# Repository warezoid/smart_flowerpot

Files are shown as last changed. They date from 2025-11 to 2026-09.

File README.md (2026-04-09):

# Smart flowerpot
The aim of the project is to create a self-sufficient and ECO-friendly planter for growing vegetables.

## Project roadmap
1. Hardware completation - finish hardware assemblies and subassemblies.
    - Drainage vent - finished.
    - Roulette system - working on.
    - Flower vent system
2. Sensors completation - solve sensor placement and data gathering.
3. User interface - create user interface with graphs, controls, logs, ...

## TODOs
- Debug drainage vent driving circuit.

- Redesign and make roulette guides.
- Program roulette driver code.

## Outdated model photos
CAD of roulette system. 
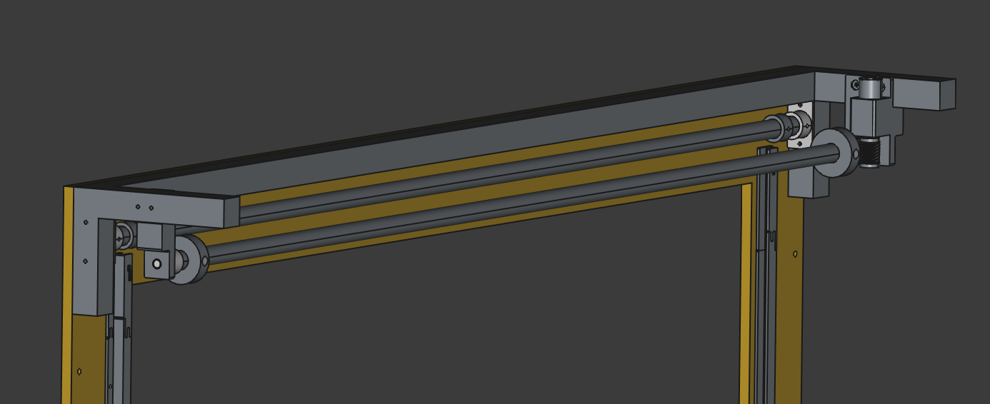
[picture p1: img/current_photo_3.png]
Outdated model photo.


CAD of drainage vent system.
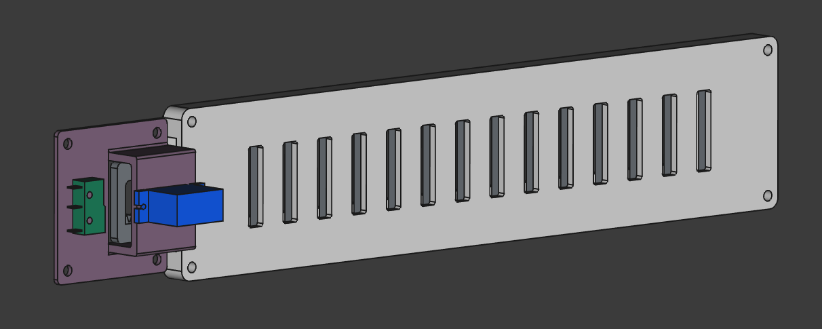
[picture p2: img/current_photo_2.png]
Outdated model photo.


CAD of older smart flower assembly.
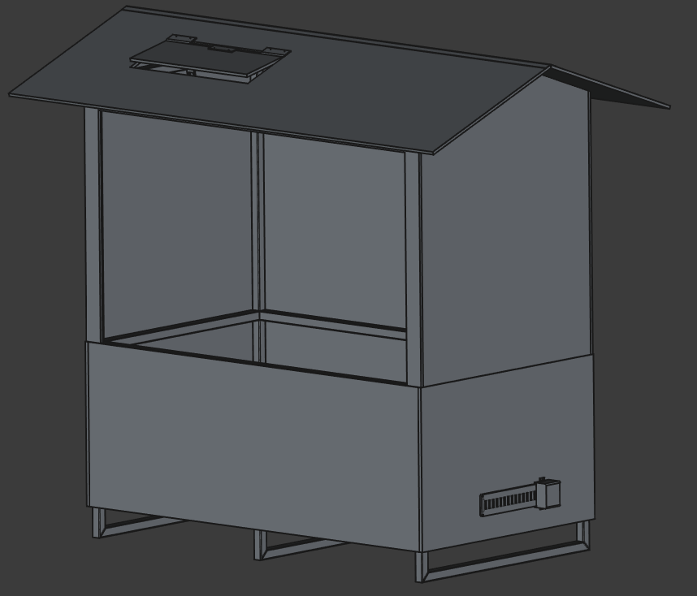
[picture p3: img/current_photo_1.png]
Outdated model photo.


###### Created by warezoid with the love of freedom and numbers.

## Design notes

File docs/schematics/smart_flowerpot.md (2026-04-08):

# Smart flowerpot
This document is overview of progress and TODOs on smart flowerpot project.

## Construction - **COMPLETE BY THE END OF MAY**
- Finish welding:
    - Weld roof and bottom together.
    - Grind all welds.
    - Check length, perpendicularity and levelness.
    - Paint construction by some color.
    - Update warezoid.com page: update metal profile photo and finished steel frame.
    - Add FEM section of metal frame.

- OSB + polycarbonate:
    - Plan OSB and polycarbonate from walls and roof - create CAD files.
        - https://www.hornbach.cz/p/polykarbonatova-deska-bravo-dutinkova-3000-x-1050-x-10-mm-cira/8234584/
    - OSB FEM sources:
        - https://www.drevoostrava.cz/cz/osb-desky/ostra-hrana/3-swiss-krono-osb-3-18-x-1250-x-2500.html?varianta=3
        - https://regata.b-cdn.net/media/folio3/productattachments/SKHU_Technical_Data_EN_2025_03_03.pdf
        - https://europanels.org/the-wood-based-panel-industry/types-of-wood-based-panels-economic-impact/oriented-strand-board/
        - https://hrcak.srce.hr/file/263350

## ESP32 / DRIVERs / MOTION

### Drainage vent
- Repair vent driver electronics (**FINISH TILL 11. APR 2026**):
    - Resolder new servo.
    - Assembly new ESP32 on a board.
    - Test for shorts, poor soldering and wire brakes.
    - Put circuit description on board.

- Program update (**FINISH TILL 12. APR 2026**):
    - Update file structure of project.
    - Update GPIOs names and check their numbers to be compatible with *smartflowerpot_tech_db*.
    - Test software with hardware.

- Create servo case:
    - Plan case for vent servo and RJ45 mini-board.
    - Make CAD model - include cabel input with some default protection.
    - Print cases and add them to test stand.

## SO
- Research:
    - Grandma
    - github.com/honzagalajda

- Consultation:
    - Marťas
    - github.com/MichalKonvic
    - github.com/zombon1

- Making stage help:
    - Honzajs

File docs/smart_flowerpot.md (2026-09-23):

# Smart flowerpot
This document is overview of progress and TODOs on smart flowerpot project.

## TODOs
- Add some RPI web server notes - MAN/AUTO mode, ...

## To buy
- Flower vent:
    - BOTTOM VENT:                   
        - MOTOR DRIVERS: https://botland.cz/ovladace-motoru-moduly/22594-mp6550-jednokanalovy-ovladac-motoru-22v-17a-pololu-4733.html

## Project roadmap
- Version 1: create functional sample of smart flowerpot.
    - Current phase:
        - Mechanical phase:
            - Create and make smartflowerpot structure.
            - Steel frame, OSB, polycarbonate, 3d printing.
            - CAD, FEM, 3d printing.
            - Output should be physical structure of smartflowerpot without drivers, sensors and electronics.

        - Driver phase:
            - Create hardware and software drivers for smart flowerpot.
            - Drainage vent, roulette, flower vent & roof vent.
            - Water circuit driver, solar power recharge.
            - Software, hardware, electronics.
            - Output should be functional drivers.

    - Sensor phase:
        - Place sensors for watering, overview, ventilation, ...
        - Create some algorithms for data procesing.
        - Output should be updated table with sensor data.
        - Coding, electronics, logic, simple table database.

    - Master-slave phase:
        - Create communication between MASTER (RPi) and multiple slaves (ESP32).
        - Send commands from MASTER to SLAVE, which will reply.
        - Start self-hosting webserver on RPi.
        - Create simple web GUI which will serve as commands IO.

    - Advanced master-slave phase:
        - RPi will get data from sensor ESP32 and store them in some local copy for overviews and commands.
        - Data will be checked and if needed drivers will be called to do some action.
        - Drivers will reply with action status and process is done.
        - Update GUI to more profesional form - overviews, logs, ...

- Version 1.1: fix bugs. Write potentional future improvements. See if second roulette is needed.
    - Solve some better system for holding hall sensors than hot glue - easier calibration.

- Version 2: add IR camera and add some machine vision. Pests monitoring.

## Construction
- OSB:
    - Cut needed holes into OSBs, grind them.
    - Grind some edge on roullete OSB hole - bottom edge of roulette window, roulette hit it and can be stucked (only on it's way down).
    - Paint OSBs by some protective paint.
    - Drill holes for OSBs mounting.
    - Add thread to the holes.
    - Repaint steel construction - drilled holes only.
    - Mount walls to the steel construction.

    - OSB FEM sources:
        - https://www.drevoostrava.cz/cz/osb-desky/ostra-hrana/3-swiss-krono-osb-3-18-x-1250-x-2500.html?varianta=3
        - https://regata.b-cdn.net/media/folio3/productattachments/SKHU_Technical_Data_EN_2025_03_03.pdf
        - https://europanels.org/the-wood-based-panel-industry/types-of-wood-based-panels-economic-impact/oriented-strand-board/
        - https://hrcak.srce.hr/file/263350

- Post-finish works:
    - Update metal profile photo and finished steel frame section.
    - Add FEM section of metal frame.

- Polycarbonate:
    - Plan OSB and polycarbonate from walls and roof - create CAD files.
        - https://www.hornbach.cz/p/polykarbonatova-deska-bravo-dutinkova-3000-x-1050-x-10-mm-cira/8234584/

## ESP32 / DRIVERs / FLOWER VENT
- Create some ventilation system for flowers:
    - Add big holes to bottom section of side OSBs with some simple ventilation - OPEN, CLOSE states.
    - Also add smaller holes to top of sided OSBs, also with some simple ventilation.
    - At top holes add fans, to create some wind channel.

- TOP vent:
    - Solve construction of top vent.
    - Solve fan system.

- BOTTOM vent:
    - *TODOs*:
        - Make hole in both shafts bigger on motor side - from 5 mm to 6 mm.
        - Think about ideal screw rod length. Cut it and file it.
        - Print motor holder, rod holder and flange, to future test.
        - Try to build some test stand - without doors.
        - Create doors.

    - Use construction of two trapezoidal screws.
    - One motor through shaft will be rotating with screw rod. Slider will be attached to desk.
    - At top will be some flange and belt transfering rotation to second pair of rods.
    - At bottom position and top position will be limit switches.
    - I also want to add some linear position measurement, for future use - some PID regulation of position. For example vent will be open to 50 %, 20 %, 75 %, ...
    - I would buy trapezoidal screws with slider, shaft, motor (if needed also with driver), LS, linear position measurement, belt, ball bearings.
    - I would print flanges, maybe belt holders, desk holders, other holders, ...

## ESP32 / DRIVERs / MOTION
- Check driver schematics with real circuit and update it if needed.
- Check CAD files if they are same as reality.

- Upgrade Excel table.
    - Separate MOTION to diferent lists, ....
- Create bill of material table for all drivers.

- Do some last testing of circuit before epoxy cover.
- Cover circuit in epoxy resin to prevent shorts and add some protection.

### Roulette
- Recalibrate TOP Hall sensor - TOP GREEN probably.

## Documentation

### warezoid.com
- Project description.
- Pictures.
- Guide.
- TODOs.
- Roadmap.
- DOCs.
- Download links.

### Documentation
- Construction: steele frame, OSB, polycarbonate, FEM.
- Drivers: drainage vent system, roulette system, flower vent system.
- Sensors, RPI server, communication, ...

## SO
- Research:
    - Grandma
    - github.com/honzagalajda

- Consultation:
    - Marťas
    - github.com/MichalKonvic
    - github.com/zombon1

- Making stage help:
    - Honzajs

## Notes

### Drivers/FLOWER VENT
- Flower vent:
    - BOTTOM VENT (only one piece):
        - MOTOR (1 pcs / 258 CZK): https://www.laskakit.cz/motor-jgy-370-12v-s-prevodovkou/
        - SHAFT (1 pcs / 44 CZK): https://www.laskakit.cz/pruzna-spojka-hlinikova-sviraci-5x8mm/
        - SCREW (1 pcs / 322 CZK): http://www.snailshop.cz/t8/2832-pohybovy-sroub-t8-500mm.html
        - NUT (2 pcs / 144 CZK): http://www.snailshop.cz/t8/2375-matice-s-prirubou-t8-mosaz.html
        
        - PULLEY (2 pcs / 112 CZK): http://www.snailshop.cz/remenice-gt2-oble-zuby/2354-remenice-gt2-20-zubu-dira-8mm.html
        - BELT (1 pcs / 76 CZK): http://www.snailshop.cz/remeny-gt2-oble-zuby/2586-ozubeny-remen-gt2-160-zubu-320mm.html
        - WORM SCREW (3 packs / 24 CZK): http://www.snailshop.cz/m3/1992-sroub-staveci-m3x5-4ks.html
        - BEARING (10 pcs / 200 CZK): http://www.snailshop.cz/bez-priruby/2826-688-lozisko-8x16x5.html
            
        - MOTOR DRIVERS: https://botland.cz/ovladace-motoru-moduly/22594-mp6550-jednokanalovy-ovladac-motoru-22v-17a-pololu-4733.html

### Drivers/MOTION/Drainage vent
- FSM:
    - IDLE (0):
        - Scan for process code. If process code (in control byte) is 00 then break. If not, then copy&paste control byte process code to temporary byte process code. Set state machine to 1 and breake.
        - Commands will be set by process code bits: 00 non active, 01 opening, 10 closing, 11 spare, in future maybe calibration.
        - Program will read only from temporary process code, which can be set only in IDLE, so overriding should be solved.
    
    - Start 1 (1):
        - If vent 1 is enabled then set action_start_ticks, set power mosfet 1 to ON, and set PWM for given operation for vent 1. Then set state machine to 2 and break.
        - Otherwise set state machine to 3 and break.

    - Moving 1 (2):
        - Check for given limit switch and if switch is active then switch off PWM, set power mosfet 1 to OFF and null action_start_ticks. Set state machine bit to 3 and break.
        - If limit switch is not active, then check if current_ticks - action_start_ticks are bellow given time interval. If yes, just break. If no, then  switch off PWM, set power mosfet 1 to OFF and null action_start_ticks and block vent 1 - set vent 1 enable bit to 0. Then set state machine bit to 3 and break.

    - Start 2 (3):
        - If vent 2 is enabled then set action_start_ticks, set power mosfet 2 to ON, and set PWM for given operation for vent 2. Then set state machine to 4 and break.
        - Otherwise set state machine to 5 and break.

    - Moving 2 (4):
        - Check for given limit switch and if switch is active then switch off PWM, set power mosfet 2 to OFF and null action_start_ticks. Then acknowledge - set vent 2 enable bit to 1. Set state machine bit to 5 and break.
        - If limit switch is not active, then check if current_ticks - action_start_ticks are bellow given time interval. If yes, just break. If no, then  switch off PWM, set power mosfet 2 to OFF and null action_start_ticks and block vent 2 - set vent 2 enable bit to 0. Then set state machine bit to 5 and break.
    
    - Finish (5):
        - Null control byte process code, temporary process code.
        - Set state machine bit to 0 and breake.

### Drivers/MOTION/Roulette
- FSM:
    - IDLE (0):
        - Scan for process code. If process code (in io_byte) is 00 then break. If not, then copy&paste io_byte process code to temporary byte process code. Set state machine to 1 and breake.
        - Commands will be set by process code bits: 00 non active, 01 opening, 10 closing, 11 spare, in future maybe calibration.
        - Program will read only from temporary process code, which can be set only in IDLE, so overriding should be solved.
    
    - Start 1 (1):
        - If roulette is enabled then set action_start_ticks, set direction pins and enable to ON. Then set state machine to 2 and break.
        - Otherwise set state machine to 4 and break.

    - Moving 1 (2):
        - Check for given limit switch and if one of them is active then switch off enable pin, null action_start_ticks and set direction pins to 0. Set state machine bit to 3 and break.
        - If limit switch is not active, then check if current_ticks - action_start_ticks are bellow given time interval. If yes, just break. If no, then switch off enable pin, set direction pins to 0, null action_start_ticks and block roulette 1 - set roulette 1 enable bit to 0. Then set state machine bit to 4 and break.

    - Acknowledge (3):
        - Check if both limit switch for given movement are active, if not then alarm user but not block the code. If yes just ignore it. Set it to 4 and break.

    - Finish (4):
        - Null control byte and io_byte process code, temporary process code.
        - Set state machine bit to 0 and breake.

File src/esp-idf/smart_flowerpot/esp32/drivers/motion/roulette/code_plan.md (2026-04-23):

# Roulette driver

## Code
1. Debuging.

## Problems
- Main problem is that I need somehow always stop the motor -> without relaying on ESP or some driver.
    - Potentional solution:
        - Physicly add some guards which will block weight from some places - bellow and above guides.
        - Normal run -> hall effect sensors connected to ESP.
            - Weight magnet reference with sensor -> ESP get notification -> switch off motor power.
            - Operation will set check index and ESP will check it in main program loop. (index 0 -> check nothing, index > 0 -> check up, index < 0 -> check down)
            - To stop motor 2 sensors will be in OR mode, to check if position is valid use AND mode.
        - Emergency -> limit switch (msw13 microswitch) physicaly behind hall efffect sensor (upper or lower) -> normaly close -> in series with motor power -> if active (error) motor shuts down.
            - This is emergency stop in electrical layer.
            - If ESP goes down -> no problem -> NC switch connected with motor power in series.
            - If motor or motor driver goes down -> motor will not spin -> no problem -> ESP set motor to block and sent alerts.
        - Emergency 2 -> try to get motor driver with overcurrent protection -> if motor is drawing too much current it will switch off power to motor.
            - Use MP6550 motor driver.

## Code diagram
1. Get OPEN/CLOSE request.
2. If operation open/close isn't already running then do:
    1. If roulette is not blocked then do:
        1. Set motor direction.
        2. Set Hall effect check index - lower or higher hall effect will be checked.
        3. Switch on power to motor & Start callback timer and ticks.
        4. Check for Hall effect senzor status change.
            1. If valid status changed then switch off power to motor - main switch off!
            - There are two hall effect sensors for top and two for bottom.
            - In this checkout hall effect sensors in one section will work in OR mode -> one or both must be active else dont stop.
        5. After timer collapse callback will switch off power to motor - EVERYTIME - emergency switch off!
        6. After ticks collapse check if roulette is in valid position if not:
            1. Set roulette to blocked status.
            - In this checkout hall effect sensors in one section will work in AND mode -> both must be active else block.
        7. Clear ticks, hall effect check index, ...
        8. Return.
3. Ignore request.

- DIR signal will be same for both roulettes. Signals 11 and 00 means non active state. 01 is direction one and 10 is direction two.
- Motor will be stoped by driver electronics.
- ESP only set enable signal and read limit switches. ESP can also block one roulette.
- Roulette default state is CLOSED.
- ESP have to drive Enable and DIR signals.

##### Created by warezoid with the love of freedom and numbers <3

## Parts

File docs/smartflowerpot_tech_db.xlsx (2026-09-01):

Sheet: MAIN
MAIN
FOLDER STRUCTURE
LAYER 1 | LAYER 2 | LAYER 3 | LAYER 4 | LAYER 5 | LAYER 6 | LAYER 7 | LAYER 8 | LAYER 9 | LAYER 10
smart_flowerpot | esp32 | drivers | motion | drainage_vent | include | drainage_vent.h
 |  |  |  |  | drainage_vent.c
 |  |  |  |  | CMakeLists.txt
 |  |  |  | roulette | include | roulette.h
 |  |  |  |  | roulette.c
 |  |  |  |  | CMakeLists.txt
 |  |  |  |  | code_plan.md
 |  |  |  | flower_vent
 |  |  |  | build | …
 |  |  |  | main | motion_main.c
 |  |  |  |  | CMakeLists.txt
 |  |  |  | CMakeLists.txt
 |  |  |  | sdkconfig
 | libraries | pwm_generator | include | pwm_generator.h
 |  |  | pwm_generator.c
 |  |  | CMakeLists.txt

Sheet: DRIVERs
DRIVERs
MOTION
ESP32 GPIO PINOUT
ID | NAME |  |  | PIN | DESCRIPTION |  |  |  |  |  |  |  | SECTION |  |  | NOTE
1 | 5V |  |  | 5V | Power 5V.
2 | GND |  |  | GND | GND.
3 | EN |  |  | EN | ESP32 sleep/enable pin.
4 | TX |  |  | GPIO1 | Serial communication transmit pin. |  |  |  |  |  |  |  | COMMUNICATION
5 | RX |  |  | GPIO3 | Serial communication receive pin.
6 | OUT_DRAIN_VENT_PWM |  |  | GPIO13 | PWM output for drainage vent servos. |  |  |  |  |  |  |  | DRAINAGE_VENT
7 | OUT_DRAIN_VENT_SPM1 |  |  | GPIO32 | DO for drainage vent power mosfet V1 – servo power mosfet 1.
8 | OUT_DRAIN_VENT_SPM2 |  |  | GPIO33 | DO for drainage vent power mosfet V2 - servo power mosfet 2.
9 | IN_DRAIN_VENT_ESO1 |  |  | GPIO35 | DI (only) for drainage vent V1 open position end switch - end switch open 1.
10 | IN_DRAIN_VENT_ESO2 |  |  | GPIO39 | DI (only) for drainage vent V2 open position end switch - end switch open 2.
11 | IN_DRAIN_VENT_ESC1 |  |  | GPIO34 | DI (only) for drainage vent V1 close position end switch - end switch close 1.
12 | IN_DRAIN_VENT_ESC2 |  |  | GPIO36 | DI (only) for drainage vent V2 close position end switch - end switch close 2.
13 | OUT_ROULETTE_EN1 |  |  | GPIO16 | DO for roulette R1 motor driver enable pin – enable 1. |  |  |  |  |  |  |  | ROULETTE
14 | OUT_ROULETTE_DIR1 |  |  | GPIO18 | DO for roulette R1 motor driver direction bit 1 – direction 1.
15 | OUT_ROULETTE_DIR2 |  |  | GPIO19 | DO for roulette R1 motor driver direction bit 2 – direction 1.
16 | IN_ROULETTE_TOP1 |  |  | GPIO22 | DI for roulette R1 open position hall sensors – top 1.
17 | IN_ROULETTE_TOP2 |  |  | GPIO23 | DI for roulette R1 open position hall sensors – top 2.
18 | IN_ROULETTE_BOT1 |  |  | GPIO17 | DI for roulette R1 close position hall sensors – bottom 1.
19 | IN_ROULETTE_BOT2 |  |  | GPIO21 | DI for roulette R1 close position hall sensors – bottom 2.
20 | SPARE |  |  | GPIO4 | Spare pin. |  |  |  |  |  |  |  | SPARE
21 | SPARE |  |  | GPIO25 | Spare pin.
22 | SPARE |  |  | GPIO26 | Spare pin.
23 | SPARE |  |  | GPIO27 | Spare pin.
ESP-IDF TIMERS
ID | NAME |  |  | PIN | DESCRIPTION |  |  |  |  |  |  |  | SECTION
1 | SYS_DRAIN_VENT_PWM_TIME |  |  | LEDC_TIMER_0 | Drainage vent servo PWM timer. |  |  |  |  |  |  |  | DRAINAGE_VENT
ESP-IDF CHANNELS
ID | NAME |  |  | PIN | DESCRIPTION |  |  |  |  |  |  |  | SECTION
1 | SYS_DRAIN_VENT_PWM_CHNL |  |  | LEDC_CHANNEL_0 | Drainage vent servo PWM channel. |  |  |  |  |  |  |  | DRAINAGE_VENT
DRAINAGE VENT
STRUCTS
ID | NAME |  |  | FILE |  | ATRIBUTE TYPE |  |  | ATRIBUTE NAME |  |  | DESCRIPTION
1 | ledc_timer_config_t | vsrp_dataset | vsrp_dataset | ledc.h |  | ledc_mode_t |  |  | speed_mode |  |  | Configuration structure for LEDC TIMER.
 |  |  |  |  |  | ledc_timer_t |  |  | timer_num
 |  |  |  |  |  | ledc_timer_bit_t |  |  | duty_resolution
 |  |  |  |  |  | uint32_t |  |  | freq_hz
 |  |  |  |  |  | ledc_clk_cfg_t |  |  | clk_cfg
2 | ledc_channel_config_t |  |  |  |  | ledc_mode_t |  |  | speed_mode |  |  | Configuration structure for LEDC CHANNEL.
 |  |  |  |  |  | ledc_channel_t |  |  | channel
 |  |  |  |  |  | ledc_timer_t |  |  | timer_sel
 |  |  |  |  |  | ledc_intr_type_t |  |  | intr_type
 |  |  |  |  |  | int |  |  | gpio_num
 |  |  |  |  |  | uint32_t |  |  | duty
 |  |  |  |  |  | int |  |  | hpoint
3 | pwm_generator_config_t |  |  | pwm_generator.h |  | ledc_timer_t |  |  | timer |  |  | Configuration structure for PWM GENERATOR.
 |  |  |  |  |  | ledc_channel_t |  |  | channel
 |  |  |  |  |  | uint32_t |  |  | freq_hz
 |  |  |  |  |  | int |  |  | out_pin
4 | drainage_vent_dataset_t | vsrp_dataset | vsrp_dataset | drainage_vent.h |  | TickType_t |  |  | action_start_tick |  |  | Dataset structure which store drainage vent runtime properties.
 |  |  |  |  |  | uint32_t |  |  | v1_opn_ms
 |  |  |  |  |  | uint32_t |  |  | v1_cls_ms
 |  |  |  |  |  | uint32_t |  |  | v2_opn_ms
 |  |  |  |  |  | uint32_t |  |  | v2_cls_ms
 |  |  |  |  |  | uint32_t |  |  | v1_opn_duty
 |  |  |  |  |  | uint32_t |  |  | v1_cls_duty
 |  |  |  |  |  | uint32_t |  |  | v2_opn_duty
 |  |  |  |  |  | uint32_t |  |  | v2_cls_duty
 |  |  |  |  |  | uint16_t |  |  | err_word
 |  |  |  |  |  | uint8_t |  |  | io_byte
 |  |  |  |  |  | uint8_t |  |  | ctrl_byte
BIT STRUCTURES
ID |  | BYTE | BIT | DATA | READ BIN MASK |  | READ HEX MASK |  |  | ID |  | BYTE | BIT | DATA |  | READ BIN MASK | READ HEX MASK
1 |  | 1 | B0 | SPARE |  |  |  |  |  | 2 |  | 1 | B0 | PROCESS CODE |  | 0b0000 0011 | 0x03
 |  |  | B1 | SPARE |  |  |  |  |  |  |  |  | B1
STRUCTURE |  |  | B2 | SPARE |  |  |  |  |  | STRUCTURE |  |  | B2 | SPARE
drainage_vent_dataset_t |  |  | B3 | SPARE |  |  |  |  |  | drainage_vent_dataset_t |  |  | B3 | SPARE
 |  |  | B4 | SPARE |  |  |  |  |  |  |  |  | B4 | VENT 1 ENABLED |  | 0b0001 0000 | 0x10
ATRIBUTE |  |  | B5 | SPARE |  |  |  |  |  | ATRIBUTE |  |  | B5 | VENT 2 ENABLED |  | 0b0010 0000 | 0x20
err_word |  |  | B6 | SPARE |  |  |  |  |  | io_byte |  |  | B6 | SPARE
 |  |  | B7 | SPARE |  |  |  |  |  |  |  |  | B7 | SPARE
DATA TYPE |  | 2 | B8 | SPARE |  |  |  |  |  | DATA TYPE
uint16_t |  |  | B9 | SPARE |  |  |  |  |  | uint8_t
 |  |  | B10 | SPARE
 |  |  | B11 | SPARE
 |  |  | B12 | SPARE
 |  |  | B13 | SPARE
 |  |  | B14 | SPARE
 |  |  | B15 | SPARE
ID |  | BYTE | BIT | DATA | READ BIN MASK |  | READ HEX MASK |  |  | FSM STATES |  |  | PROCESS CODE
3 |  | 1 | B0 | FSM STATE | 0b0000 1111 |  | 0x0F |  |  | 0 | IDLE |  | 0 | OFF
 |  |  | B1 |  |  |  |  |  |  | 1 | START 1 |  | 1 | OPEN
STRUCTURE |  |  | B2 |  |  |  |  |  |  | 2 | MOVING 1 |  | 2 | CLOSE
drainage_vent_dataset_t |  |  | B3 |  |  |  |  |  |  | 3 | START 2 |  | 3 | SPARE
 |  |  | B4 | TMP PROCESS CODE | 0b0011 0000 |  | 0x30 |  |  | 4 | MOVING 2
ATRIBUTE |  |  | B5 |  |  |  |  |  |  | 5 | FINISH
ctrl_byte |  |  | B6 | SPARE
 |  |  | B7 | SPARE
DATA TYPE
uint8_t
DUPONT & UTP CABLE CONNECTION
CABLE | COLOR 1 | COLOR 2 | DESCRIPTION |  |  | DUPONT terminal – TOP view
1 |  |  | +10V |  |  | +10V |  | +10V |  | +6V |  | PWM
2 |  |  | ESO |  |  | ESO |  | ESC |  | GND |  | GND
3 |  |  | +10V |  |  |  |  |  |  |  |  |  | ARROW
4 |  |  | ESC
5 |  |  | +6V
6 |  |  | GND
7 |  |  | PWM
8 |  |  | GND
ROULETTE
STRUCTS
ID | NAME |  |  | FILE |  | ATRIBUTE TYPE |  |  | ATRIBUTE NAME |  |  | DESCRIPTION
1 | roulette_dataset_t |  |  | roulette.h |  | TickType_t | vsrp_dataset | vsrp_dataset | action_start_tick |  |  | Dataset structure which store roulette runtime properties.
 |  |  |  |  |  | uint32_t |  |  | r1_opn_ms
 |  |  |  |  |  | uint32_t |  |  | r1_cls_ms
 |  |  |  |  |  | uint16_t |  |  | err_word
 |  |  |  |  |  | uint8_t |  |  | io_byte
 |  |  |  |  |  | uint8_t |  |  | ctrl_byte
BIT STRUCTURES
ID |  | BYTE | BIT | DATA | READ BIN MASK |  | READ HEX MASK |  |  | ID |  | BYTE | BIT | DATA |  | READ BIN MASK | READ HEX MASK
1 |  | 1 | B0 | SPARE |  |  |  |  |  | 2 |  | 1 | B0 | PROCESS CODE |  | 0b0000 0011 | 0x03
 |  |  | B1 | SPARE |  |  |  |  |  |  |  |  | B1
STRUCTURE |  |  | B2 | SPARE |  |  |  |  |  | STRUCTURE |  |  | B2 | SPARE
roulette_dataset_t |  |  | B3 | SPARE |  |  |  |  |  | roulette_dataset_t |  |  | B3 | SPARE
 |  |  | B4 | SPARE |  |  |  |  |  |  |  |  | B4 | ROULETTE 1 ENABLED |  | 0b0001 0000 | 0x10
ATRIBUTE |  |  | B5 | SPARE |  |  |  |  |  | ATRIBUTE |  |  | B5 | SPARE
err_word |  |  | B6 | SPARE |  |  |  |  |  | io_byte |  |  | B6 | SPARE
 |  |  | B7 | SPARE |  |  |  |  |  |  |  |  | B7 | SPARE
DATA TYPE |  | 2 | B8 | SPARE |  |  |  |  |  | DATA TYPE
uint16_t |  |  | B9 | SPARE |  |  |  |  |  | uint8_t
 |  |  | B10 | SPARE
 |  |  | B11 | SPARE
 |  |  | B12 | SPARE
 |  |  | B13 | SPARE
 |  |  | B14 | SPARE
 |  |  | B15 | SPARE
ID |  | BYTE | BIT | DATA | READ BIN MASK |  | READ HEX MASK |  |  | FSM STATES |  |  |  | PROCESS CODE
3 |  | 1 | B0 | FSM STATE | 0b0000 1111 |  | 0x0F |  |  | 0 | IDLE |  |  | 0 | OFF
 |  |  | B1 |  |  |  |  |  |  | 1 | START 1 |  |  | 1 | OPEN
STRUCTURE |  |  | B2 |  |  |  |  |  |  | 2 | MOVING 1 |  |  | 2 | CLOSE
roulette_dataset_t |  |  | B3 |  |  |  |  |  |  | 3 | ACKNOWLEDGE |  |  | 3 | SPARE
 |  |  | B4 | TMP PROCESS CODE | 0b0011 0000 |  | 0x30 |  |  | 4 | FINISH
ATRIBUTE |  |  | B5
ctrl_byte |  |  | B6 | SPARE
 |  |  | B7 | SPARE
DATA TYPE
uint8_t
DUPONT & UTP CABLE CONNECTION
CABLE | COLOR |  | DESCRIPTION |  |  | DUPONT connector – TOP view
1 |  |  | +10V |  |  | SIGNAL |  | GND |  | +10V
2 |  |  | GND |  |  |  |  |  |  |  | ARROW
3 |  |  | SIGNAL

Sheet: MOTION DIAGRAM
 | 6V
VENT 1 | X | X
 | X | X
 | X | X |  |  |  |  |  |  |  | DRAINAGE VENT DRIVER
 | X | X
VENT 2 | X | X
 | X | X
 | X | X |  |  |  |  |  |  |  |  | 3.3V
 | X | X
 |  |  |  |  | ESP32
 |  |  |  |  | 5V
 |  |  |  |  | USB |  |  |  |  |  | 5V
 |  |  |  |  |  |  |  |  | GND
 |  |  |  |  | CD4069UBE (NOT)
 |  |  | MOTOR DRIVER |  | GND
 |  |  |  | !SLP |  |  | VDD
 |  |  |  |  | MHB4012 (NAND) |  |  |  |  | ROULETTE DRIVER
MOTOR |  |  | OUT1 | IN1 | GND
 |  |  | OUT2 | IN2 |  |  | VDD
 |  |  | GND | GND | CD4069UBE (NOT) |  |  |  |  |  | BOT 2
 |  |  | VIN |  |  | VDD |  |  |  |  | BOT 1
 |  |  |  |  |  |  |  |  |  |  | TOP 2
 |  |  |  |  | GND |  |  |  |  |  | TOP 1
 | 12V |  |  |  |  |  |  | 10V

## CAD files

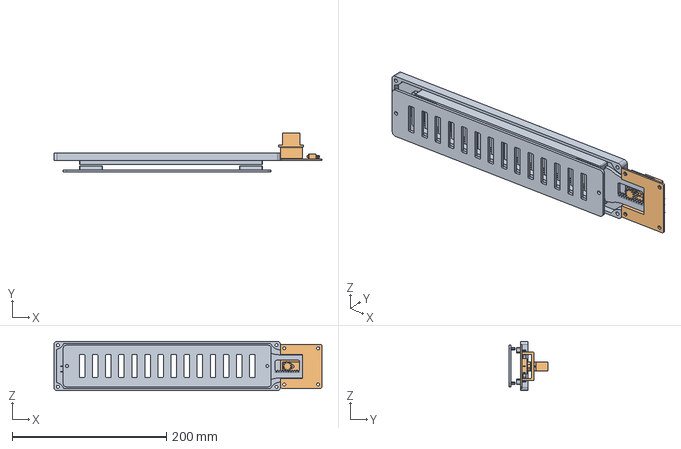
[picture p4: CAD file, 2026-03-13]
3d/cad/drainage_vent/assembly_drainage_vent.FCStd
348.0 x 51.0 x 64.0 mm
subassembly_grid_001
subassembly_servo_001

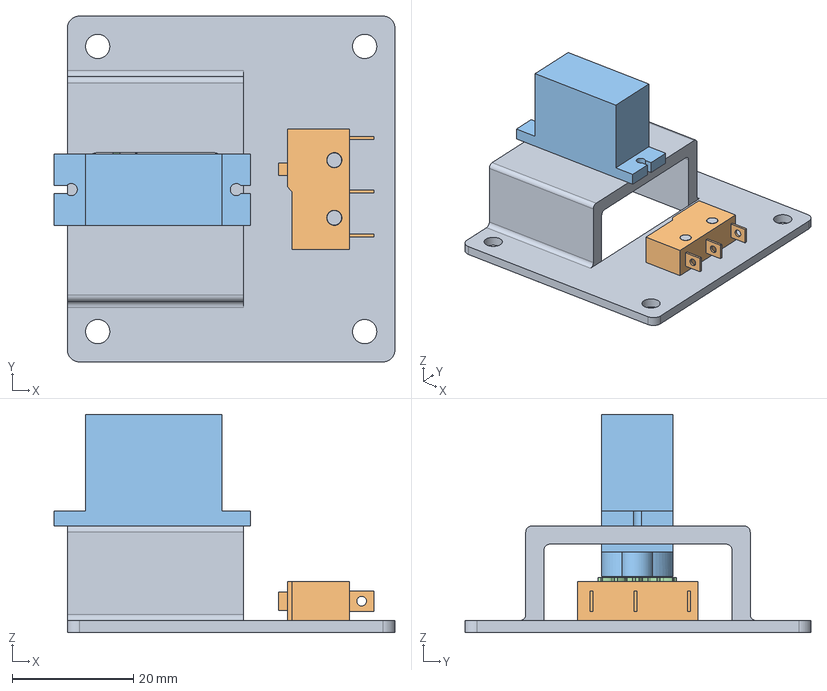
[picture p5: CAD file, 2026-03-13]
3d/cad/drainage_vent/subassemblies/subassembly_servo.FCStd
56.2 x 57.0 x 36.0 mm
servo_holder_001
msw13_microswitch_001
sg90_servo_001
servo_gear_001

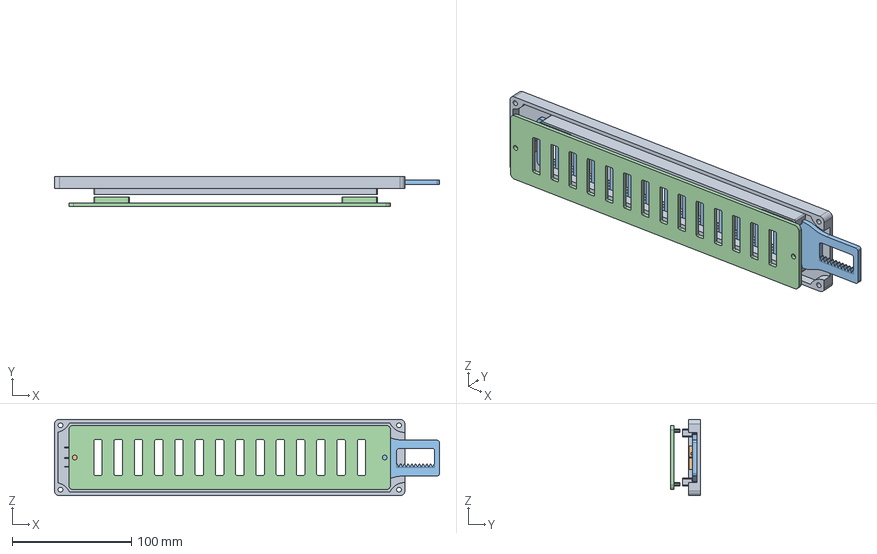
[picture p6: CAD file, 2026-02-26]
3d/cad/drainage_vent/subassemblies/subassembly_grid.FCStd
323.0 x 25.0 x 64.0 mm
grid_out_body_001
msw13_microswitch_001
grid_slider_001
grid_in_body_001

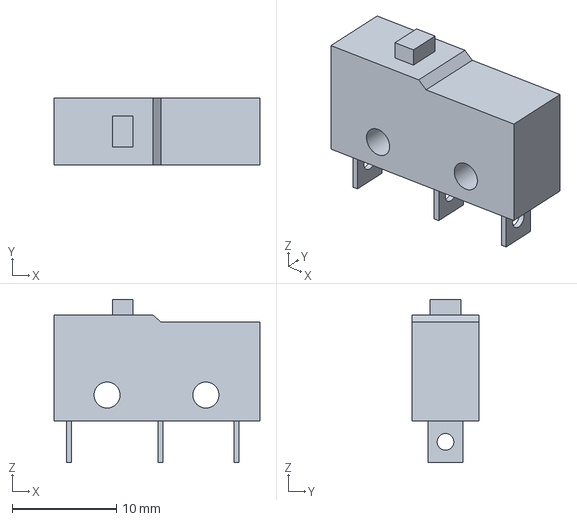
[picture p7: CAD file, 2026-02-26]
3d/cad/drainage_vent/parts/models/msw13_microswitch.FCStd
19.8 x 6.40 x 15.7 mm

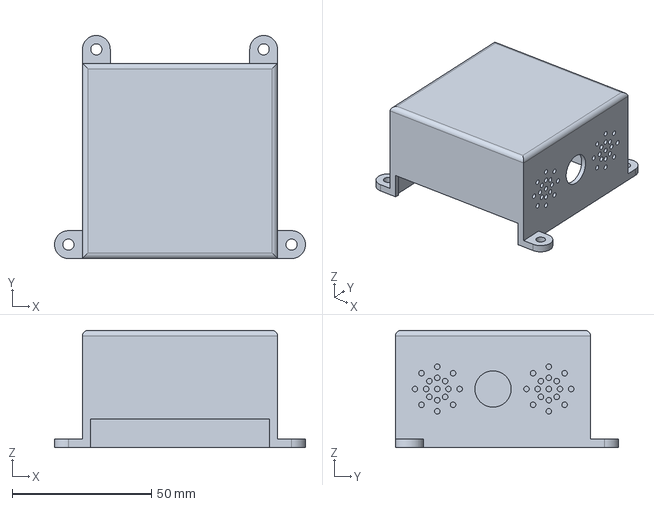
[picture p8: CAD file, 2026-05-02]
3d/cad/drainage_vent/parts/servo_case.FCStd
90.0 x 80.0 x 42.0 mm

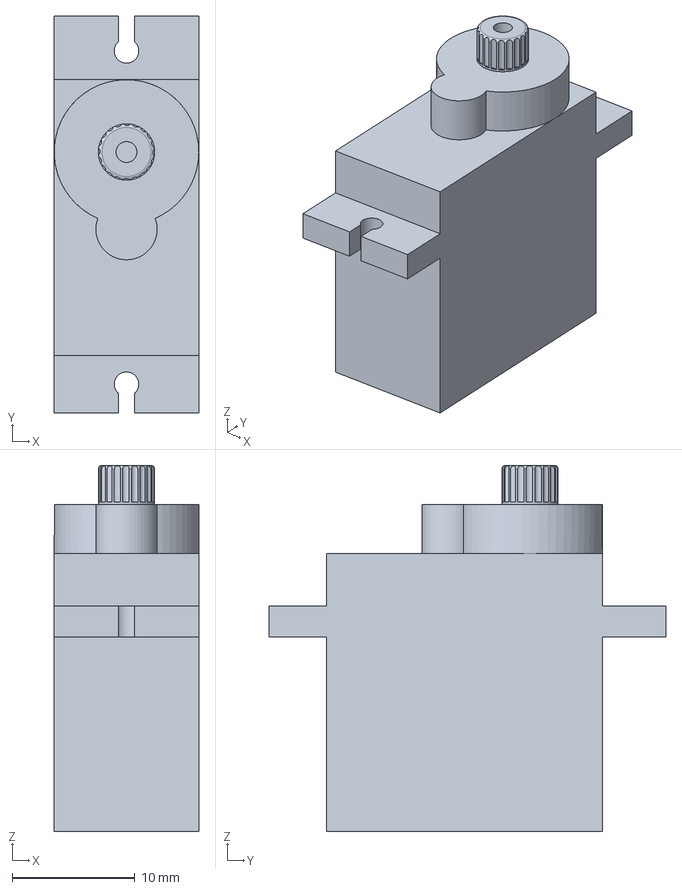
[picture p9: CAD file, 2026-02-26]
3d/cad/drainage_vent/parts/models/sg90_servo.FCStd
11.8 x 32.4 x 29.9 mm

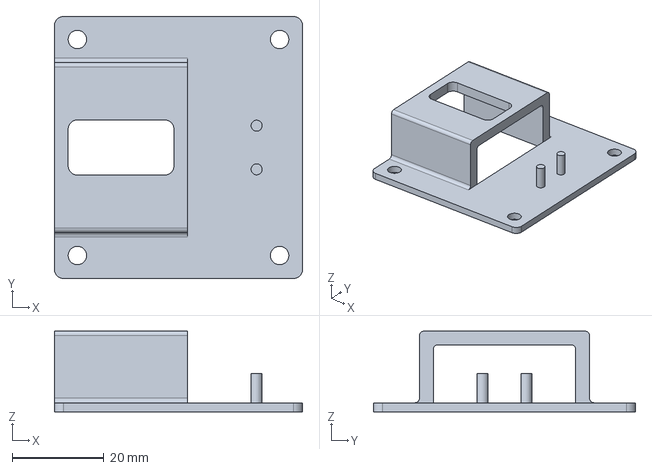
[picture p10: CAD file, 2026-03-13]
3d/cad/drainage_vent/parts/servo_holder.FCStd
54.0 x 57.0 x 17.6 mm

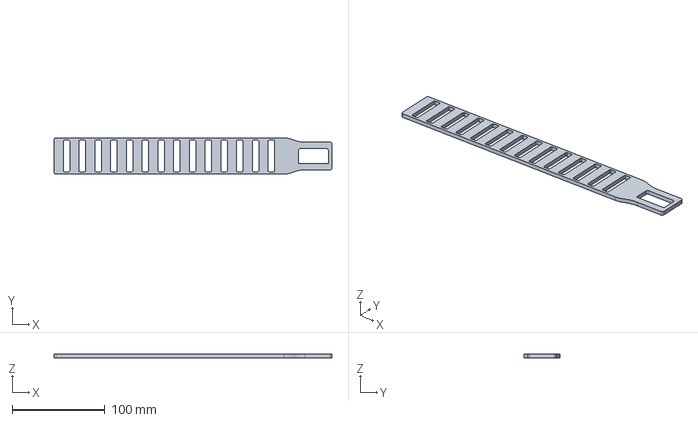
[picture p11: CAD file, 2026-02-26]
3d/cad/drainage_vent/parts/slider_body.FCStd
300.0 x 39.2 x 3.80 mm

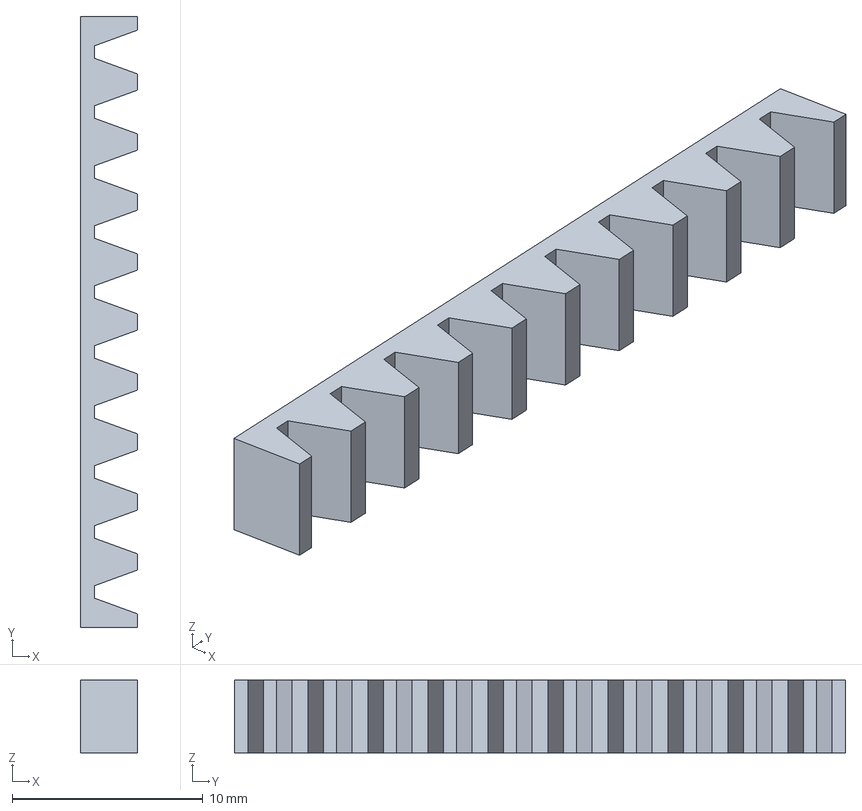
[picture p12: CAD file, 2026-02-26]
3d/cad/drainage_vent/parts/slider_rack.FCStd
3.00 x 32.0 x 3.80 mm

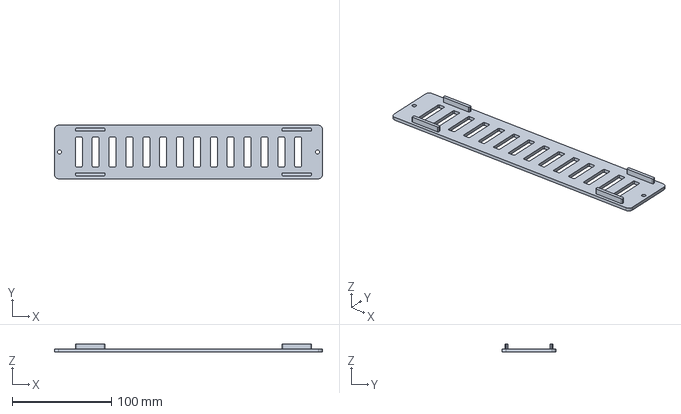
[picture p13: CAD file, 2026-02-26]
3d/cad/drainage_vent/parts/grid_in_body.FCStd
270.0 x 54.0 x 8.00 mm

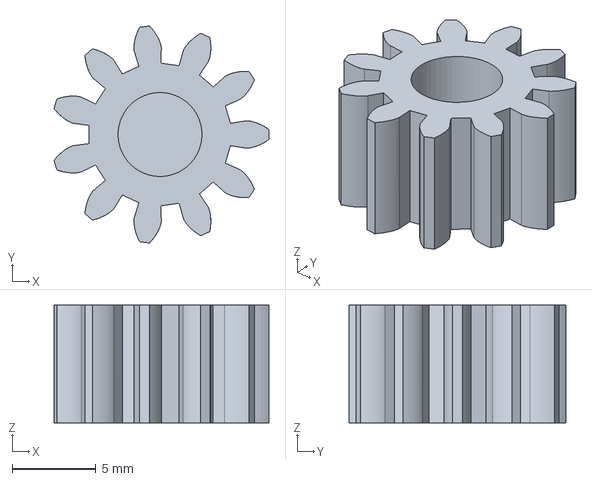
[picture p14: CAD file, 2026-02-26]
3d/cad/drainage_vent/parts/servo_gear.FCStd
12.8 x 12.9 x 7.00 mm

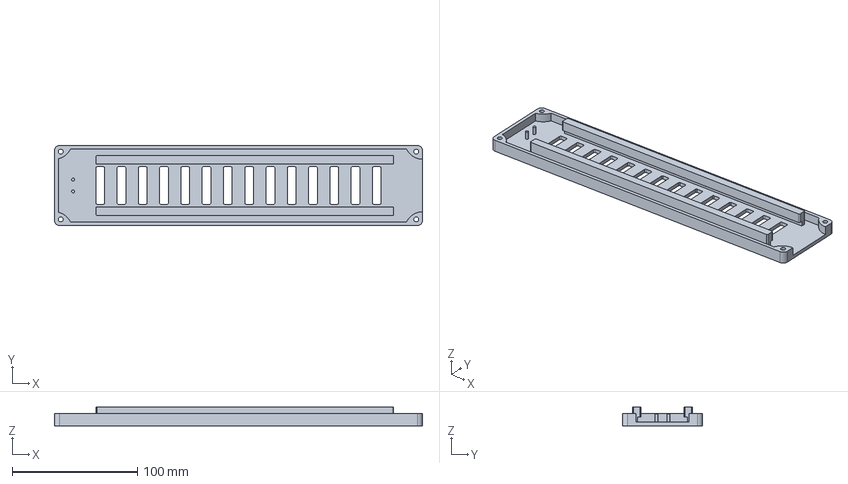
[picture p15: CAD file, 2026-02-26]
3d/cad/drainage_vent/parts/grid_out_body.FCStd
294.0 x 64.0 x 15.0 mm

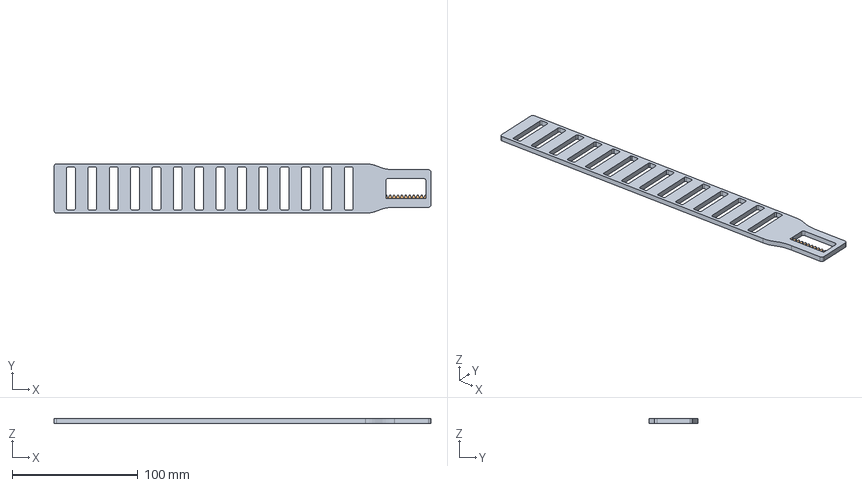
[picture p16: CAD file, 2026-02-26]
3d/cad/drainage_vent/parts/grid_slider.FCStd
300.0 x 39.2 x 3.80 mm
slider_body_001
slider_rack_001

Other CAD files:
3d/stl/drainage_vent/grid_in_body.stl
3d/stl/drainage_vent/grid_out_body.stl
3d/stl/drainage_vent/grid_slider.stl
3d/stl/drainage_vent/servo_case.stl
3d/stl/drainage_vent/servo_gear.stl
3d/stl/drainage_vent/servo_holder.stl

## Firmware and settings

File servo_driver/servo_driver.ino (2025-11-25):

#include <ESP32Servo.h>

#define VENT_SERVO_LEFT_PIN 26
#define VENT_SERVO_RIGHT_PIN 25
#define VENT_SERVO_MIN 0
#define VENT_SERVO_MAX 80

Servo vent_servo_left, vent_servo_right;
short vent_servo_pos = VENT_SERVO_MIN;

void move_servo(int pos){
  vent_servo_left.write(pos);
  vent_servo_right.write(pos);
}
short calc_move(float open_rate){
  if(open_rate <= 1){
    if(open_rate >= 0){
      return (short)(open_rate * VENT_SERVO_MAX);
    }

    return VENT_SERVO_MIN;
  }

  return VENT_SERVO_MAX;
}



/*
  - maximalni delka requestu 100 znaku + 0 (ukoncovaci)
  - command -> prvnich 10 znaku | pole: + 0 ukoncovaci 

  -> SET___MOVE <FLOAT-NUMBER> <COMMAND-TERMINATOR>
*/

#define max_request_length 101
#define max_command_length 11
#define request_terminator '\n'
#define request_padding '_'

char request[max_request_length];
char command[max_command_length];
int request_index = 0;



void print_buf(char *buf, int len){
  printf("%s\n", buf);
  
  for(int i = 0; i < len; i++){
    printf("%d ", (unsigned char)buf[i]);
  }

  printf("\n");
}



void get_command(){
  int i = 0;
  memset(command, 0, sizeof(command));

  for(int j = 0; j < (max_command_length - 1); j++){
    if(request[j] != request_padding){
      command[i] = request[j];
      i++;
    }
  }

  command[max_command_length - 1] = 0;
}
void identify_request(){
  get_command();

  print_buf(command, max_command_length);
}
void read_serial(){
  while(Serial.available()){
    char c = Serial.read();

    if(c == request_terminator){
      request[max_request_length - 1] = 0;

      identify_request();

      request_index = 0;
      memset(request, 0, sizeof(request));
    }
    else{
      if(request_index < max_request_length){
        request[request_index] = c;
        request_index++;
      }
    }
  }
}



void setup(){
  vent_servo_left.attach(VENT_SERVO_LEFT_PIN);
  vent_servo_right.attach(VENT_SERVO_RIGHT_PIN);

  Serial.begin(115200);
}

/*

  -> servo is lagged in vent_servo_pos by executive unit (EU)
  -> by sensor unit (SU) is calculated open_rate and is send request to EU to move_servo
  -> EU catch request call calc_move, which set vent_servo_pos
  -> servo is lagged... and respond with OK status
  -> REPEAT

*/

int i = 0;

void loop(){
  move_servo(vent_servo_pos);
  read_serial();
}

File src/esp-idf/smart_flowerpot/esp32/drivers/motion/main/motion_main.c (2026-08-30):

#include "drainage_vent.h"
#include "roulette.h"



/*************** START of temp code - ROULETTE and VENT testing */
#define TMP_VENT_OPEN GPIO_NUM_4
#define TMP_VENT_CLOSE GPIO_NUM_27
#define TMP_ROULETTE_OPEN GPIO_NUM_25 
#define TMP_ROULETTE_CLOSE GPIO_NUM_26
/*************** END of temp code - ROULETTE and VENT testing */



void app_main(void){
/*************** START of temp code - ROULETTE and VENT testing */
    gpio_set_direction(TMP_VENT_OPEN, GPIO_MODE_INPUT);
    gpio_set_direction(TMP_VENT_CLOSE, GPIO_MODE_INPUT);
    gpio_set_direction(TMP_ROULETTE_OPEN, GPIO_MODE_INPUT);
    gpio_set_direction(TMP_ROULETTE_CLOSE, GPIO_MODE_INPUT);
/*************** END of temp code - ROULETTE and VENT testing */

//init
drainage_vent_init();
drainage_vent_dataset_t drainage_vent_sys = drainage_vent_init_dataset();

roulette_init();
roulette_dataset_t roulette_sys = roulette_init_dataset();




//loop
    while(1){
        /*************** START of temp code - ROULETTE and VENT testing */
        printf("\033[H\033[J");

        if(gpio_get_level(TMP_VENT_OPEN)){
            printf("V-LOG:\topen request!\n");
            drainage_vent_sys.io_byte = (drainage_vent_sys.io_byte & 0xFC) | 0x01;
        }

        if(gpio_get_level(TMP_VENT_CLOSE)){
            printf("V-LOG:\tclose request!\n");
            drainage_vent_sys.io_byte = (drainage_vent_sys.io_byte & 0xFC) | 0x02;
        }

        if(gpio_get_level(TMP_ROULETTE_OPEN)){
            printf("R-LOG:\topen request!\n");
            roulette_sys.io_byte = (roulette_sys.io_byte & 0xFC) | 0x01;
        }

        if(gpio_get_level(TMP_ROULETTE_CLOSE)){
            printf("R-LOG:\tclose request!\n");
            roulette_sys.io_byte = (roulette_sys.io_byte & 0xFC) | 0x02;
        }
        /*************** END of temp code - ROULETTE and VENT testing */



        //drainage_vent_print(&drainage_vent_sys);
        drainage_vent_fsm(&drainage_vent_sys);


        roulette_print(&roulette_sys);
        roulette_fsm(&roulette_sys);

        //vTaskDelay(pdMS_TO_TICKS(1));
        vTaskDelay(pdMS_TO_TICKS(100));
    }
}

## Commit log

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2025-12-13 [ Version 0.0.2.12.8 ] - roulette assembly was redesigned.
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2026-01-30 [ Version 0.0.8.3 ] - back vent and vent assembly was created in CAD.
2026-01-31 [ Version 0.0.8.4 ] - vent servo holder was added to CAD.
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2026-02-02 [ Version 0.0.9.1 ] - vent servo assembly was tryed and calibrated.
2026-02-04 [ Version 0.0.9.3 ] - vent system cut power functionality was added.
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2026-02-12 [ Version 0.0.9.6 ] - non gear flang was created in CAD.
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2026-02-23 [ Version 0.0.9.13 ] - Hall sensors was added to roulette CAD.
2026-02-26 [ Version 0.0.11 ] - drainage vent cad was added.
    [assembly_drainage_vent.FCStd, endswitch_holder.FCStd, endswitch_holder.stl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]
2026-03-02 [ Version 0.0.14 ] - roulette driver problem potentional solution was updated.
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2026-03-07 [ Version 0.0.16 ] - roulette with worm gear was added to CAD.
2026-03-13 [ Version 0.0.18 ] - vent servo holder CAD was updated.
    [assembly_drainage_vent.FCStd, endswitch_holder.FCStd, endswitch_holder.stl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]
2026-03-20 [ Version 0.0.19.1 ] - new TODOs for communication of devices was added.
2026-04-07 [ Version 0.0.20 ] - drainage vent electro was added.
    [vent_schematic.fzz]
2026-04-08 [ Version 0.0.21 ] - DOCs was added.
    [smartflowerpot_tech_db.xlsx]
2026-04-10 [ Version 0.0.21.4 ] - drainage vent electronics tasks was done.
    [smartflowerpot_tech_db.xlsx]
2026-04-11 [ Version 0.0.24.5 ] - drainage vent GPIOs was updated.
    [smartflowerpot_tech_db.xlsx]
2026-04-11 [ Version 0.0.24.6 ] - drainage vent folder structure was updated.
    [smartflowerpot_tech_db.xlsx]
2026-04-12 [ Version 0.0.24.7 ] - drainage vent program was updated.
    [smartflowerpot_tech_db.xlsx]
2026-04-12 [ Version 0.0.24.8 ] - drainage vent program was finished.
    [smartflowerpot_tech_db.xlsx]
2026-04-13 [ Version 0.0.24.9 ] - roulette temporary GPIOs was added to Excel.
    [smartflowerpot_tech_db.xlsx]
2026-04-14 [ Version 0.0.25 ] - roulette driver schematic was added.
    [smartflowerpot_tech_db.xlsx, vent_schematic.fzz]
2026-04-15 [ Version 0.0.25.1 ] - excel GPIOs was updated.
    [smartflowerpot_tech_db.xlsx]
2026-04-15 [ Version 0.0.26 ] - roulette docs was updated & file structure was init.
    [smartflowerpot_tech_db.xlsx]
2026-04-16 [ Version 0.0.26.2 ] - roulette header was updated.
    [smartflowerpot_tech_db.xlsx]
2026-04-17 [ Version 0.0.26.3 ] - some roulette code was written.
    [smartflowerpot_tech_db.xlsx]
2026-04-18 [ Version 0.0.26.4 ] - motion esp32 schematic was added.
    [smartflowerpot_tech_db.xlsx]
2026-04-19 [ Version 0.0.26.8 ] - roulette code was debuged and filtering TODO was added.
2026-05-02 [ Version 0.0.27.4 ] - DOCs was updated and servo_case 3d files was added.
    [servo_case.FCStd, servo_case.stl]
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2026-06-13 [ Version 0.0.28.5 ] - steel construcion was welded, ground and measured.
2026-06-14 [ Version 0.0.28.6 ] - drainage vent TODOs was done.
    [smartflowerpot_tech_db.xlsx]
2026-06-15 [ Version 0.0.28.7 ] - drainage vent RJ45 pinout was updated.
    [smartflowerpot_tech_db.xlsx]
2026-06-15 [ Version 0.0.28.8 ] - drainage vent bit optimalization was done.
    [smartflowerpot_tech_db.xlsx]
2026-06-15 [ Version 0.0.28.9 ] - roulette files was modified only for one roulette.
    [smartflowerpot_tech_db.xlsx]
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2026-06-16 [ Version 0.0.28.11 ] - 3 hall sensors was mounted on test stand and TODOs was updated.
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2026-06-19 [ Version 0.0.28.15 ] - debuging of roulette driver breadboard circuit has started. New bugs was founded.
    [motion_main.c, roulette.c, roulette.h]
2026-06-21 [ Version 0.0.28.17 ] - some work on roulette driver debugging was done. New bugs was found.
    [roulette.c]
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2026-06-27 [ Version 0.0.29.2 ] - TESTING 3 was done. TOP yellow sensor is broken and will need to be repaired or replaced.
    [motion_main.c, roulette.c, roulette.h]
2026-06-28 [ Version 0.0.29.3 ] - TOP yellow hall sensor was replaced - need to be calibrated.
    [roulette.h]
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2026-07-09 [ Version 0.0.29.11 ] - soldering repair of NOR gate was done. Also short was repaired.
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2026-07-23 [ Version 0.0.29.16 ] - motor driver circuit inputs were soldered. Short test was done.
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2026-07-25 [ Version 0.0.29.18 ] - roulette driver circuit was tested. Future TODOs were added.
    [smartflowerpot_tech_db.xlsx]
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2026-08-02 [ Version 0.0.30.1 ] - vent driver UTP dupont cables were created.
    [smartflowerpot_tech_db.xlsx]
2026-08-02 [ Version 0.0.30.2 ] - servo side vent drivers were created.
    [smartflowerpot_tech_db.xlsx]
2026-08-03 [ Version 0.0.30.3 ] - new servo driver was build on breadboard.
    [smartflowerpot_tech_db.xlsx]
2026-08-04 [ Version 0.0.30.4 ] - breadboard circuit was debuged. Some bugs were found, but circuit is working.
    [smartflowerpot_tech_db.xlsx]
2026-08-05 [ Version 0.0.30.5 ] - OSBs were bought. Vent driver GPIOs were checked.
    [smartflowerpot_tech_db.xlsx]
2026-08-05 [ Version 0.0.30.6 ] - vent driver was recalibrated and new TODOs were written.
    [smartflowerpot_tech_db.xlsx]
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2026-08-13 [ Version 0.0.30.14 ] - drainage vent schematic and Excel diagram were updated.
    [smartflowerpot_tech_db.xlsx]
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2026-08-18 [ Version 0.0.30.18 ] - schematics were updated.
    [smartflowerpot_tech_db.xlsx]
2026-08-21 [ Version 0.0.31.0 ] - programming of new vent driver has started.
    [smartflowerpot_tech_db.xlsx]
2026-08-22 [ Version 0.0.31.1 ] - FSM first states code were writen.
    [smartflowerpot_tech_db.xlsx]
2026-08-23 [ Version 0.0.31.2 ] - FSM code was writen.
    [smartflowerpot_tech_db.xlsx]
2026-08-24 [ Version 0.0.31.3 ] - roulette and vent driver debugging started. Both are not working. :(
    [drainage_vent.c, motion_main.c, roulette.c]
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2026-08-28 [ Version 0.0.32 ] - new GPIO pinout for roulette was created.
    [smartflowerpot_tech_db.xlsx]
2026-08-29 [ Version 0.0.32.1 ] - roulette driver was resoldered. New TODOs were added.
    [smartflowerpot_tech_db.xlsx]
2026-08-30 [ Version 0.0.32.2 ] - roulette driver code was rewrite as FSM. Everything were tested.
    [smartflowerpot_tech_db.xlsx]
2026-08-31 [ Version 0.0.32.3 ] - SPARE pins were added to Excel table.
    [smartflowerpot_tech_db.xlsx]
2026-09-01 [ Version 0.0.32.4 ] - SPARE pins wires were soldered.
    [smartflowerpot_tech_db.xlsx]
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
